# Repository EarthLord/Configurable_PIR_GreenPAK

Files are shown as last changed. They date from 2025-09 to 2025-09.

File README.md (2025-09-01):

# Project _PIR<sup>PAK</sup>_

### Objective

Create a PIR (Passive InfraRed) sensor system to detect movement using low cost AnalogPAK IC from Renesas (SLG47001). PIR sensors detect motion of heat, thus are used in security systems, building automation and wildlife conservation industries extensively. The sensitivity of sensing of movement is configurable by users using an `UP` and `DOWN` button.

### SLG47001 design 
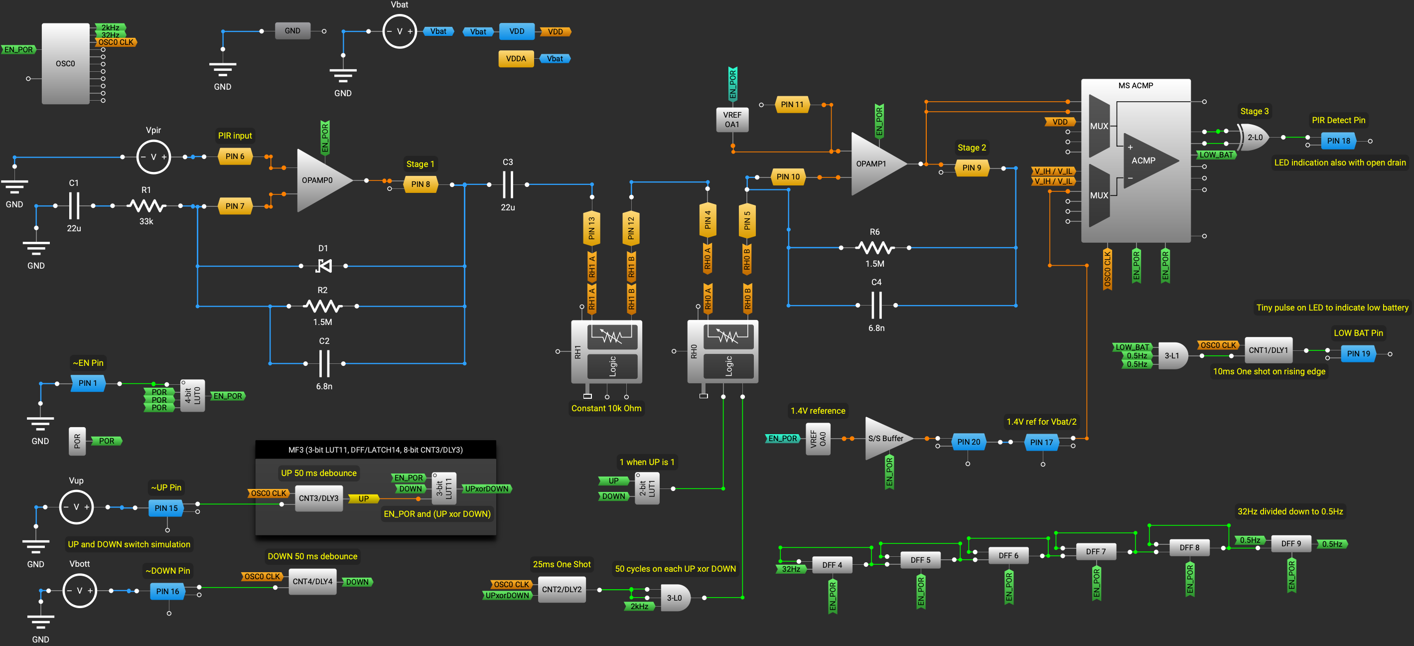
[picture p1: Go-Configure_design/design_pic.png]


### Schematic
schematic.pdf

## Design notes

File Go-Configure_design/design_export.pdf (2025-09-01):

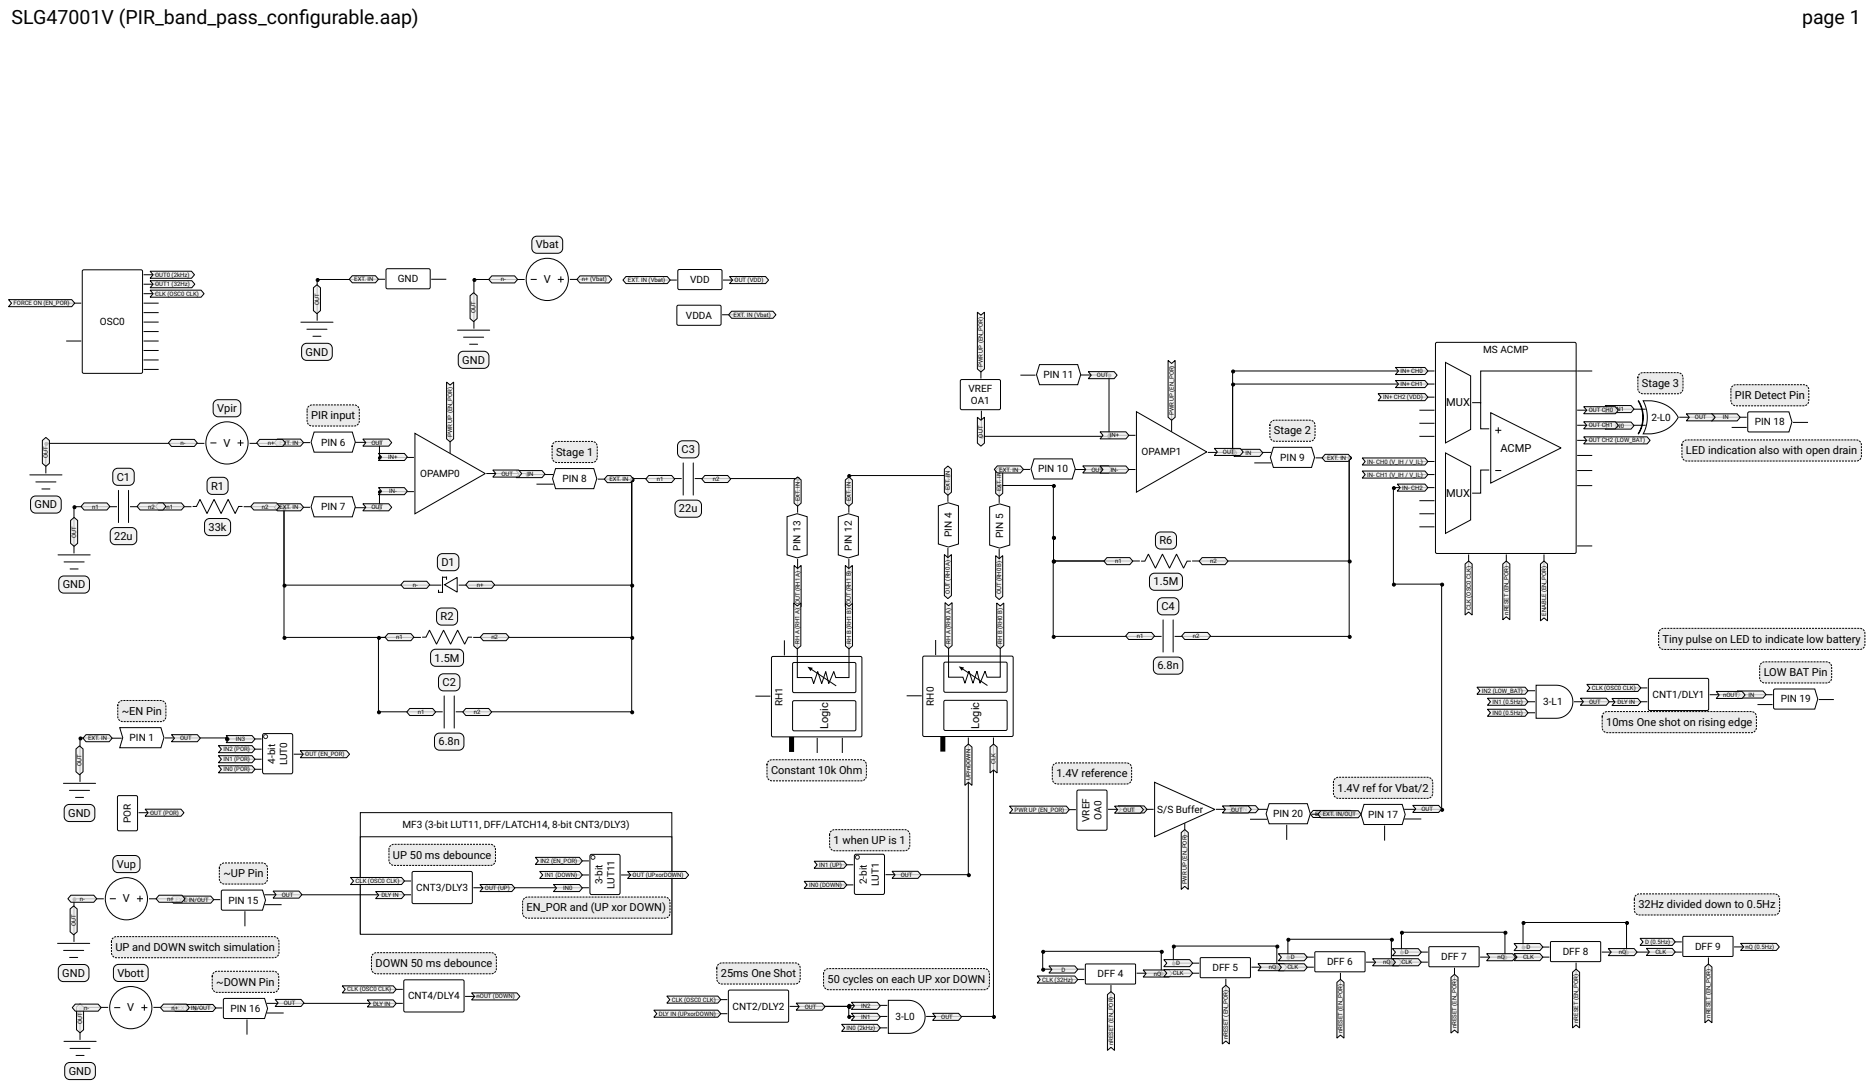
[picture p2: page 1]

LED indication also with open drain

OUT (RH0 A) EXT. IN PIN 4

OUT (RH0 B) EXT. IN PIN 5

OUT (RH1 A) EXT. IN PIN 13

OUT (RH1 B) EXT. IN PIN 12

Tiny pulse on LED to indicate low battery

DLY IN
10ms One shot on rising edge

EN_POR and (UP xor DOWN)

UP and DOWN switch simulation

50 cycles on each UP xor DOWN

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
e I/O selection | Digital input In mode | Digital in with Schmitt trig
| g e r
O u t m o d e | N o n e
R e sis t o r | P ull U p
R e sis t o r v alu e | 1 M

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
P r o p e r ty | Va l u e
Min. v alu e ( V ) | 2.4 0
Ty p. v alu e ( V ) | 3.0 0
M a x. v alu e ( V ) | 3.4 0

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
P r o p e r ty | Va l u
e I/O selection | Analog input/output In mode | Analog input/output Out mode | Analog input/output Resistor | Floating PIN 5 (RH0_B/GPI2) Property | Value I/O selection | Analog input/output In mode | Analog input/output Out mode | Analog input/output Resistor | Floating PIN 6 (OA0+) Label: "PIR input" Property | Value I/O selection | Analog input/output In mode | Analog input/output Out mode | Analog input/output

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
e I/O selection | Analog input/output In mode | Analog input/output Out mode | Analog input/output PIN 8 (OA0_OUT) Label: "Stage 1" Property | Value I/O selection | Analog input/output In mode | Analog input/output Out mode | Analog input/output PIN 9 (OA1_OUT) Label: "Stage 2" Property | Value I/O selection | Analog input/output In mode | Analog input/output Out mode | Analog input/output PIN 10 (OA1-) Property | Value I/O selection | Analog input/output In mode | Analog input/output Out mode | Analog input/output PIN 11 (OA1+) Property | Value I/O selection | Analog input/output In mode | Analog input/output Out mode | Analog input/output PIN 12 (RH1_B/GPI3) Property | Value I/O selection | Analog input/output In mode | Analog input/output Out mode | Analog input/output Resistor | Pull Down Resistor value | 1M

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
e I/O selection | Analog input/output In mode | Analog input/output Out mode | Analog input/output Resistor | Floating VDDA (PIN 14) Property | Value Min. value (V) | N/D Typ. value (V) | N/D Max. value (V) | N/D PIN 15 (GPIO0) Label: "~UP Pin" Property | Value I/O selection | Digital input In mode | Digital in with Schmitt trig
| g e r
O u t m o d e | N o n e
R e sis t o r | P ull U p
R e sis t o r v alu e | 1 M

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
P r o p e r ty | Va l u
| Digital input In mode Digital in with Schmitt trig e I/O selection
| g e r
O u t m o d e | N o n e
R e sis t o r | P ull U p
R e sis t o r v alu e | 1 M

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
P r o p e r ty | Va l u
| Analog input/output In mode Analog input/output Out mode Analog input/output Resistor Floating e I/O selection

S

L

G

V

(

### PIR

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
### ble.a

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
e I/O selection | Digital output In mode | None Out mode | 3.2x open drain NMOS Resistor | Pull Up Resistor value | 100K PIN 19 (SDA/GPIO5) Label: "LOW BAT Pin" Property | Value I/O selection | Digital output In mode | None Out mode | 3.2x open drain NMOS Resistor | Pull Up Resistor value | 100K PIN 20 (GPIO3) Property | Value I/O selection | Analog input/output In mode | Analog input/output Out mode | Analog input/output Resistor | Floating Digital Rheostat0 Property | Value Enable status | Enable EPG data to Rheostat | Disable Data mapping selection | MSB Active level for UP/DOWN | Up when HIGH Resistance (initial data) | 500 Calculated resistance | ~49.618 kOhm

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
e le

v

el f

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
(initial d

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

O

PA

M

P

1

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
P r o p e r ty | Va l u e
E n a ble s ele c tio n | F r o m r e gis t e r
R e gis t e r e n a ble | V r e f e n a
ble Input voltage selection | 2.016 V Output selection | 1408 mV High side VREF selection | Disable VREF LPF | Disable VREF OPAMP1 Property
| Va l u e
E n a ble s ele c tio n | F r o m m a t rix
R e gis t e r e n a ble | V r e f e n a
| VDD Output selection VDD * (32 / ble Input voltage selection
| 6 3 )
V R E F L P F | E n a ble

M

S

A

C

M

P

P r o p e r ty | Va l u e
M o d e s ele c tio n | S a m plin g
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
el A

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
plin

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
X in

p

u

t

S

a

m

plin

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

VDD Channel 0 IN+ gain Disable IN+ source OA1 IN- Low to High source VDD * (4 ble Input voltage selection

8

/

6

3

VDD * (48 / 63) Hysteresis - Output polarity Q Channel 1 IN+ gain Disable IN+ source OA1 IN- Low to High source VDD * (16 / 63) IN- High to Low source VDD * (16 / 63) Hysteresis - Output polarity Q Channel 2 IN+ gain x0.5 IN+ source VDD IN- Low to High source Ext. Vref (PIN 1 ) IN- High to Low source

7 ( G PIO 2 )

Ext. Vref (PIN 17 (GPIO2)) Hysteresis - Output polarity nQ ) IN- High to Low source

## 2-bit LUT0/DFF/LATCH0 Label: "Stage 3"

IN1 | IN0 | OUT
0 | 0 | 0
0 | 1 | 1
1 | 0 | 1
1 | 1 | 0
Property | Value
Type | LUT
Standard gates | XOR

## 2-bit LUT1/DFF/LATCH1 Label: "1 when UP is 1"

IN1 | IN0 | OUT
0 | 0 | 0
0 | 1 | 0
1 | 0 | 1
1 | 1 | 1
Property | Value
Type | LUT
Standard gates | | Defined by user

## 3-bit LUT0/DFF/LATCH2 Label: "50 cycles on each UP xor DOWN"

IN2 | IN1 | IN0 | OUT
0 | 0 | 0 | 0
0 | 0 | 1 | 0
0 | 1 | 0 | 0
0 | 1 | 1 | 0
1 | 0 | 0 | 0
1 | 0 | 1 | 0
1 | 1 | 0 | 0
1 | 1 | 1 | 1
Property | Value
Type | LUT
Standard gates | AND

## 3-bit LUT1/DFF/LATCH3

IN2 | IN1 | IN0 | OUT
0 | 0 | 0 | 0
0 | 0 | 1 | 0
0 | 1 | 0 | 0
0 | 1 | 1 | 0
1 | 0 | 0 | 0
1 | 0 | 1 | 0
1 | 1 | 0 | 0
1 | 1 | 1 | 1
Property | Value
Type | LUT
Standard gates | AND

## 3-bit LUT2/DFF/LATCH4

Property | Value
Type | DFF / LATCH
Mode | DFF
nSET/nRESET option | nRESET
Initial polarity | Low
Q output polarity | Inverted (nQ)
Active level for RST/SET | Low level

## 3-bit LUT3/DFF/LATCH5

Property | Value
Type | DFF / LATCH
Mode | DFF
nSET/nRESET option | nRESET
Initial polarity | Low
Q output polarity | Inverted (nQ)
Active level for RST/SET | Low level

## 3-bit LUT4/DFF/LATCH6/Shift Register 0

Property | Value
Type | DFF / LATCH
Mode | DFF
nSET/nRESET option | nRESET
Initial polarity | Low
Q output polarity | Inverted (nQ)
Active level for RST/SET | Low level

## 3-bit LUT5/DFF/LATCH7/Shift Register 1

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

## 3-bit LUT6/DFF/LATCH8/Shift Register 2

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

## 3-bit LUT7/DFF/LATCH9/Shift Register 3 Label: "32Hz divided down to 0.5Hz"

Property | Value
Type | DFF / LATCH
Mode | DFF
nSET/nRESET option | nRESET
Initial polarity | Low
Q output polarity | Inverted (nQ)
Active level for RST/SET | Low level
SLG47001V (PIR_band_pass_configurable.aap) | page 4

## 4-bit LUT0/DFF/LATCH10

IN3 | IN2 | IN1 | IN0 | OUT
0 | 0 | 0 | 0 | 0
0 | 0 | 0 | 1 | 0
0 | 0 | 1 | 0 | 0
0 | 0 | 1 | 1 | 0
0 | 1 | 0 | 0 | 0
0 | 1 | 0 | 1 | 0
0 | 1 | 1 | 0 | 0
0 | 1 | 1 | 1 | 1
1 | 0 | 0 | 0 | 0
1 | 0 | 0 | 1 | 0
1 | 0 | 1 | 0 | 0
1 | 0 | 1 | 1 | 0
1 | 1 | 0 | 0 | 0
1 | 1 | 0 | 1 | 0
1 | 1 | 1 | 0 | 0
1 | 1 | 1 | 1 | 0
Property | Value
Type | LUT
Standard gates | Defined by user

## MF1 (3-bit LUT9, DFF/LATCH12, 8-bit CNT1/DLY1)

## 8-bit CNT1/DLY1 (MF1) Label: "10ms One shot on rising edge"

Property | Value
Mode | One shot
Counter data | 20
Pulse width (typical) | 10.2539 ms
Edge mode select | Rising
DLY IN init. value | Initial 0
Output polarity | Inverted (nOUT)
Mode signal SYNC | Bypass
Clock source | OSC0
Clock frequency | 2.048 kHz

## MF2 (3-bit LUT10, DFF/LATCH13, 8-bit CNT2/DLY2)

## 8-bit CNT2/DLY2 (MF2) Label: "25ms One Shot"

Property | Value
Mode | One shot
Counter data | 50
Pulse width (typical) | 24.9023 ms
Edge mode select | Rising
DLY IN init. value | Initial 0
Output polarity | Non-inverted (OUT)
Mode signal SYNC | Bypass
Clock source | OSC0
Clock frequency | 2.048 kHz

## MF3 (3-bit LUT11, DFF/LATCH14, 8-bit CNT3/DLY3)

## 3-bit LUT11 (MF3) Label: "EN_POR and (UP xor DOWN)"

IN2 | IN1 | IN0 | OUT
0 | 0 | 0 | 0
0 | 0 | 1 | 0
0 | 1 | 0 | 0
0 | 1 | 1 | 0
1 | 0 | 0 | 0
1 | 0 | 1 | 1
1 | 1 | 0 | 1
1 | 1 | 1 | 0
Property | Value
Standard gates | Defined by user

## 8-bit CNT3/DLY3 (MF3) Label: "UP 50 ms debounce"

Property | Value
Mode | Delay
Counter data | 101
Delay time (typical) | 49.8047 ms
Edge mode select | Both
DLY IN init. value | Bypass the initial
Output polarity | Non-inverted (OUT)
Mode signal SYNC | Bypass
Clock source | OSC0
Clock frequency | 2.048 kHz

## MF4 (3-bit LUT12, DFF/LATCH15, 8-bit CNT4/DLY4)

## 8-bit CNT4/DLY4 (MF4) Label: "DOWN 50 ms debounce"

Property | Value
Mode | Delay
Counter data | 101
Delay time (typical) | 49.8047 ms
Edge mode select | Both
DLY IN init. value | Bypass the initial
Output polarity | Inverted (nOUT)
Mode signal SYNC | Bypass
Clock source | OSC0
Clock frequency | 2.048 kHz

## OSC0

Property | Value
Control pin mode | Force on
OSC power mode | Force Power On
Clock selector | OSC
'OSC0' frequency | 2.048 kHz
'CLK' predivider by | 1
'OUT0' second divider by | 1
'OUT1' second divider by | 64

## Sink/Source Buffer

Property | Value
Power up source | From register
Power up register | Enable
Input selection | OA0 VREF
Input selection from VREF | 1408 mV
SLG47001V (PIR_band_pass_configurable.aap) | page 5

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
Ele m e n t | C a p a cit o r
C a p a cit a n c e | 6.8 n F
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
allel R

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
allel R

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
allel R

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

V

b

a

t

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

m

a

x

3.3

V
T lo w | 1.7 s
T

risin

g

5

m

s
T hig h | 5 s
T f allin g | 5 m s

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

d
Ris e tim e | 1 μ s
F all tim e | 1 μ s

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
1 0 0 m s | 3 V
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
1 0 0 m s | 3 V
1 0 0 m s | 0 V
5 0 0 μ s | 3 V

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
D u ra t i o n | Vo l t a g e
1 0 0 0 m s | 3.3 V
5 m s | 0 V
5 m s | 3.3 V
5 m s | 0 V
5 m s | 3.3 V
1 0 0 m s | 0 V
1 0 0 m s | 3.3 V
1 0 0 m s | 0 V
1 0 0 m s | 3.3 V
1 0 0 m s | 0 V
1 0 0 m s | 3.3 V

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
n. | Typ. | M a
x. VDD | 2.40 | 3.00 | 3.40 Temperature (°C): | -20.00 | 25.00 | 50.00 General Settings Force bandgap on | Enable GPIO quick charge | Disable Lock status | Unlocked Pattern ID | 1

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
X: 0

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
C: 6

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
X: 0

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
C: 6

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
X: 0

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
C: 6

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
X: 0

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
C: 6

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
X: 0

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
C: 6

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
X: 0

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
C: 6

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
X: 0

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
C: 6

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
X: 0

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
C: 6

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
X: 0

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
C: 6

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
X: 0

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
C: 6

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
X: 0

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
C: 6

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
X: 0

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
C: 6

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
X: 0

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
C: 6

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
X: 0

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
C: 6

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
X: 0

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
C: 6

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
X: 0

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
C: 6

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
X: 0

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
C: 6

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
X: 0

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
C: 6

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
X: 0

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
C: 6

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
X: 0

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
C: 6

2

`

b

3

+

8 -bit C N T 4 / D LY 4 ( M F 4 ) -> n O U T | D O W N | H E X: 0 x 3 E ` b 4 D E C: 6 2 ` b 4 | +
3 -bit L U T 1 2 ( M F 4 ) -> O U T | | H E X: 0 x 3 E ` b 5 D E C: 6 2 ` b 5 | -
PIN 1 8 ( S C L / G PIO 4 ) -> O U T /I2 C -> O U T 8 | | H E X: 0 x 3 E ` b 6 D E C: 6 2 ` b 6 | -
PIN 1 9 ( S D A / G PIO 5 ) -> O U T /I2 C -> O U T 9 | | H E X: 0 x 3 E ` b 7 D E C: 6 2 ` b 7
- I2C -> OUT0 | HEX: 0x3F`b0 DEC: 63`b0 | - I2C -> OUT1 | HEX: 0x3F`b1 DEC: 63`b1 | - I2C -> OUT2/EPG -> OUT2 | HEX: 0x3F`b2 DEC: 63`b2 | - I2C -> OUT3/EPG -> OUT3 | HEX: 0x3F`b3 DEC: 63`b3 | - I2C -> OUT4/EPG -> OUT4 | HEX: 0x3F`b4 DEC: 63`b4 | - I2C -> OUT5/EPG -> OUT5 | HEX: 0x3F`b5 DEC: 63`b5 | - I2C -> OUT6/EPG -> OUT6 | HEX: 0x3F`b6 DEC: 63`b6 | - I2C -> OUT7/EPG -> OUT7 | HEX: 0x3F`b7 DEC: 63`b7 | - PIN 4 (RH0_A/GPI1) -> OUT | RH0 A | HEX: 0x40`b0 DEC: 64`b0 | - PIN 5 (RH0_B/GPI2) -> OUT | RH0 B | HEX: 0x40`b1 DEC: 64`b1 | - PIN 12 (RH1_B/GPI3) -> OUT | RH1 B | HEX: 0x40`b2 DEC: 64`b2 | - PIN 13 (RH1_A/GPI4) -> OUT | RH1 A | HEX: 0x40`b3 DEC: 64`b3 | - PIN 1 (GPI0) -> OUT | NET1 | HEX: 0x40`b4 DEC: 64`b4 | + PIN 15 (GPIO0) -> OUT | NET49 | HEX: 0x40`b5 DEC: 64`b5 | + PIN 16 (GPIO1) -> OUT | NET28 | HEX: 0x40`b6 | +

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
C: 6

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
X: 0

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
C: 6

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
X: 0

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
C: 6

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
X: 0

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
C: 6

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
X: 0

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
C: 6

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
X: 0

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
C: 6

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
X: 0

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
C: 6

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
X: 0

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
C: 6

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
X: 0

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
C: 6

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
X: 0

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
C: 6

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
X: 0

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
C: 6

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
X: 0

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
C: 6

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
X: 0

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
C: 6

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
X: 0

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
C: 6

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
X: 0

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
C: 6

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
X: 0

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
C: 6

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
X: 0

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
C: 6

7

`

b

2

+

Digit

al R

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
X: 0

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
C: 6

7

`

b

3

Digit

al R

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
X: 0

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
C: 6

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
X: 0

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
C: 6

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
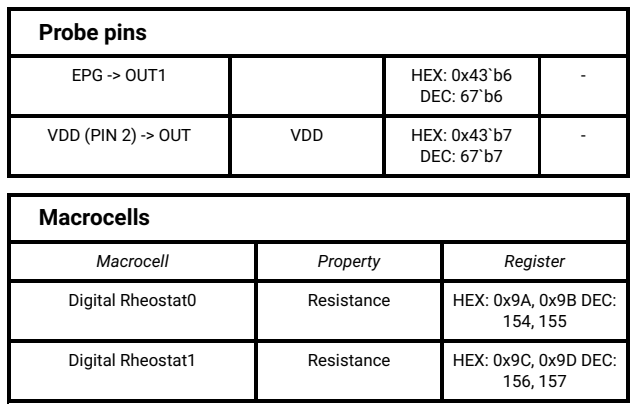
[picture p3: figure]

E P G -> O U T 1 | | H E X: 0 x 4 3 ` b 6 D E C: 6 7 ` b 6 | -
V D D ( PIN 2 ) -> O U T | V D D | H E X: 0 x 4 3 ` b 7 D E C: 6 7 ` b 7 | -
M a c r o c e l l | P r o p e r ty | R e g i s t e r
Digit al R h e o s t a t 0 | R e sis t a n c e | H E X: 0 x 9 A , 0 x 9 B D E C: 154, 155
Digit al R h e o s t a t 1 | R e sis t a n c e | H E X: 0 x 9 C , 0 x 9 D D E C: 156, 157

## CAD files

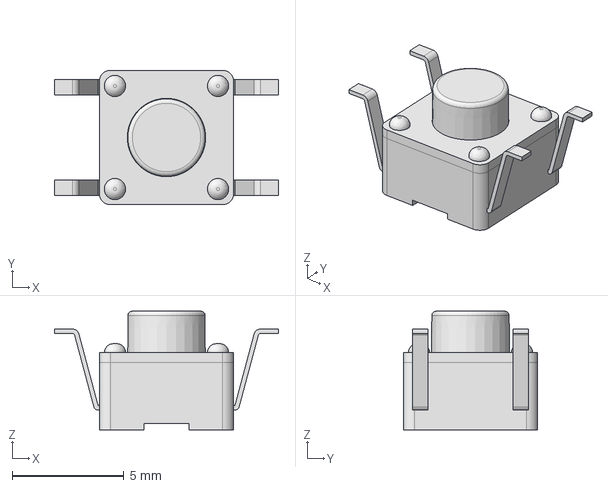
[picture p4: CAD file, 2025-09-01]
3D_models/RT3301AF100Q.stp
10.0 x 6.00 x 5.30 mm

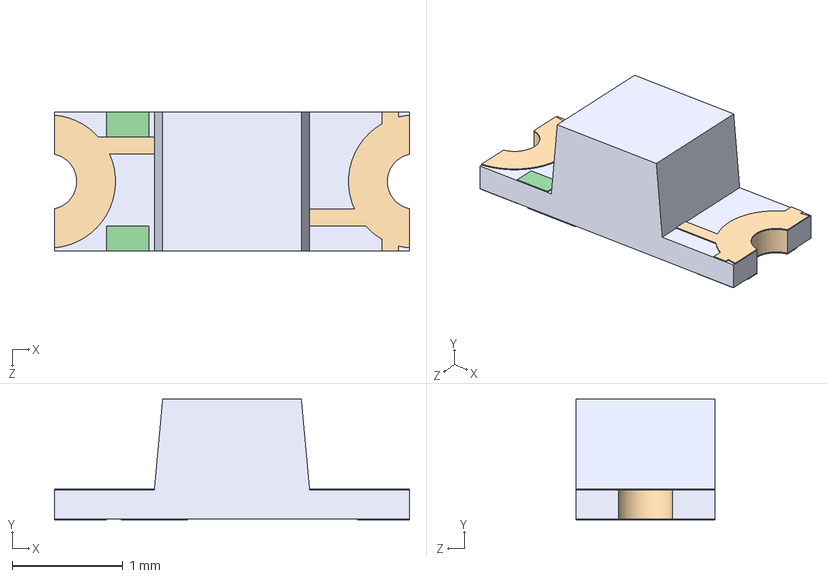
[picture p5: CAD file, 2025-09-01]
3D_models/5990Kxx_reverse_LED.stp
3.20 x 1.09 x 1.25 mm
599-0K10-107F_2
599-0K10-107F_7
599-0K10-107F_4
599-0K10-107F_6
599-0K10-107F
599-0K10-107F_1
599-0K10-107F_3
599-0K10-107F_5

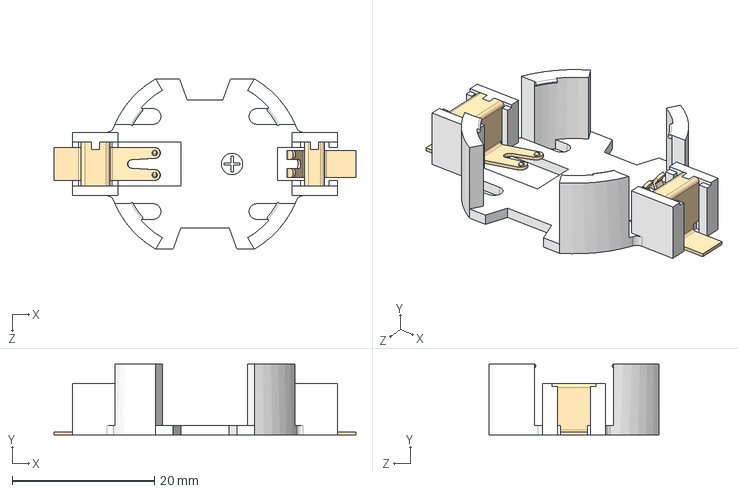
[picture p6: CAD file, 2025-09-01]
3D_models/BU2477SM-JJ-GTR.STEP
42.5 x 9.92 x 24.0 mm

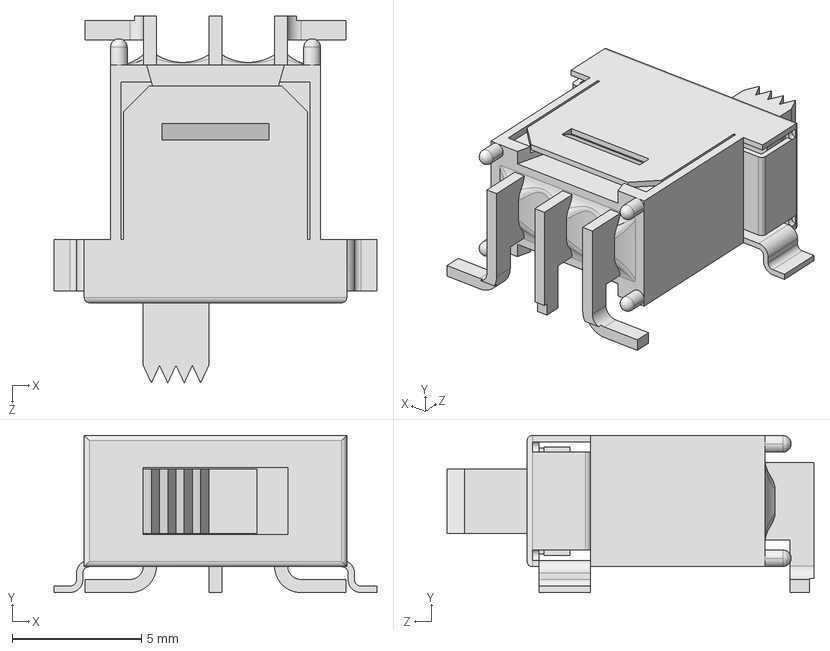
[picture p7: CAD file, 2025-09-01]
3D_models/500ASSP1SM6QE.step
12.5 x 6.08 x 14.2 mm

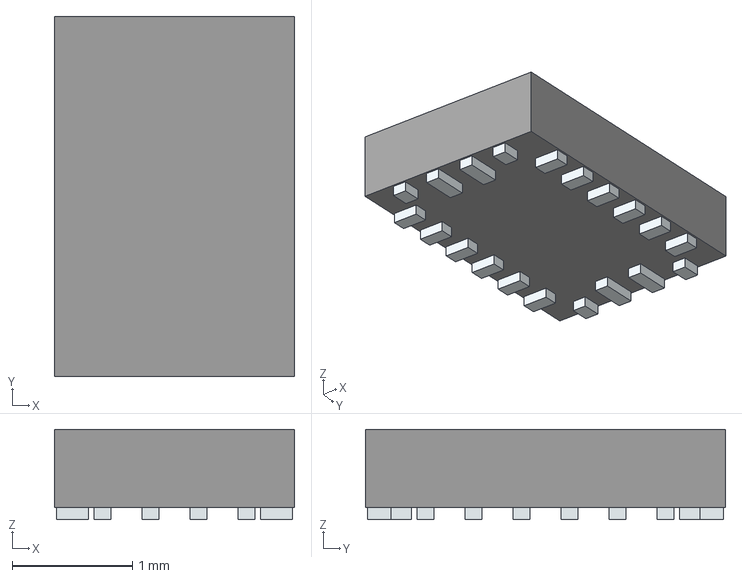
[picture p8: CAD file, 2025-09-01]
3D_models/SLG47001V.stp
2.00 x 3.00 x 0.75 mm
Pins

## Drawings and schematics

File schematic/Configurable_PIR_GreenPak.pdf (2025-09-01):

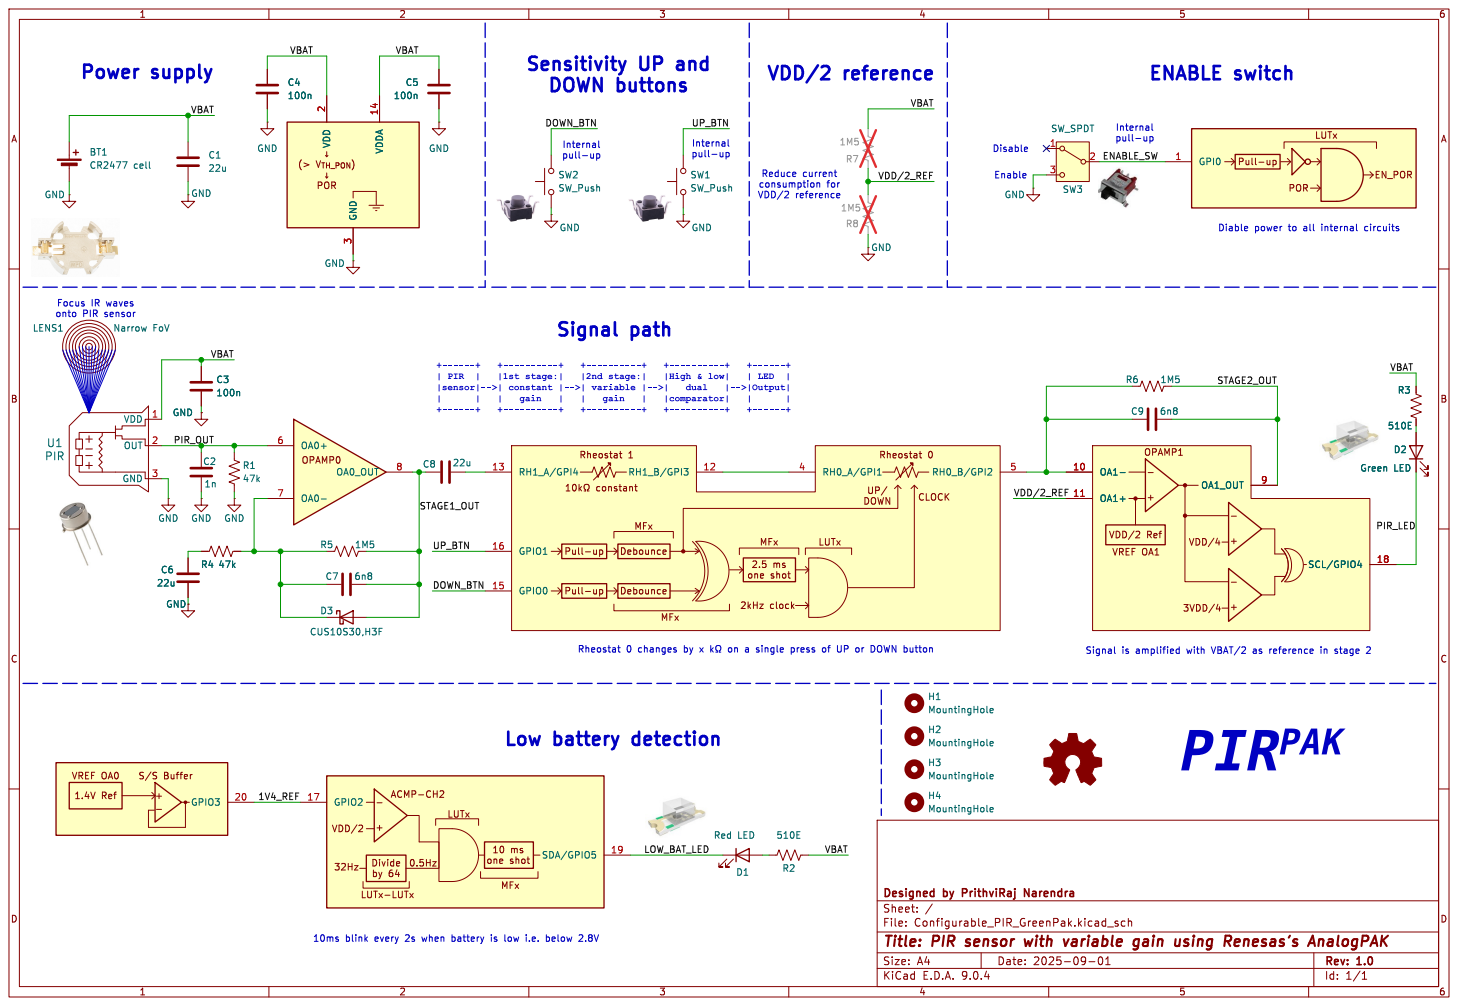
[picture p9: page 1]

Rheostat 0 changes by x þÿk©on a single press of UP or DOWN button Signal path

H4 MountingHole H3 MountingHole H2 MountingHole VREF OA0

Id: 1/1 Title: PIR sensor with variable gain using Renesas's AnalogPAK

10ms blink every 2s when battery is low i.e. below 2.8V

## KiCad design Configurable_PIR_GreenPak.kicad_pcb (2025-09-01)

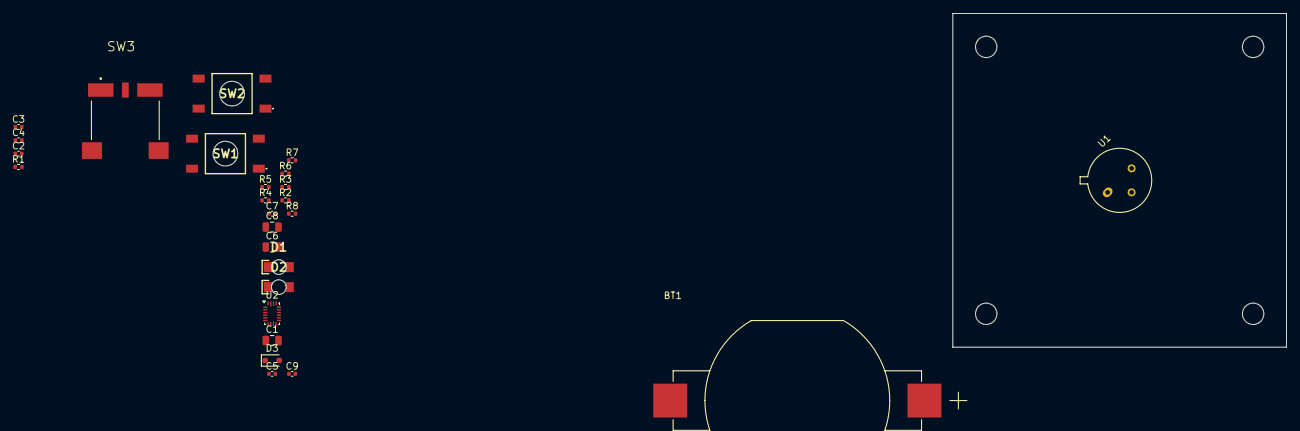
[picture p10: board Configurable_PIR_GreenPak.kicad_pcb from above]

Board: 4 copper layers, 50.0 x 50.0 mm, 30 parts (0 on the bottom side), 18 nets, no tracks yet.

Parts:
BT1: Battery_Cell; MPD_BU2477SM-JJ-GTR
C1, C6, C8: 22u; C_0805_2012Metric
C2: 1n; C_0402_1005Metric
C3, C4, C5: 100n; C_0402_1005Metric
C7, C9: 6n8; C_0402_1005Metric
D1: Red LED; 5990Kxx_reverse_LED
D2: Green LED; 5990Kxx_reverse_LED
D3: CUS10S30,H3F; D_SOD-323
H1, H2, H3, H4: MountingHole; MountingHole_3.2mm_M3
R1, R4: 47k; R_0402_1005Metric
R2, R3: 510E; R_0402_1005Metric
R5, R6, R7, R8: 1M5; R_0402_1005Metric
SW1, SW2: SW_Push; RT3301AF100Q
SW3: SW_SPDT; SW_500ASSP1SM6QE
U1: PIR; TO-5-3
U2: SLG47001V; Renesas_UQFN-20_2x3mm_P0.4mm_LayoutBorder4x6y

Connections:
/DOWN_BTN: SW2.2, U2.15 (GPIO0)
/ENABLE_SW: SW3.2 (B), U2.1 (GPI0)
/LOW_BAT_LED: D1.1 (K), U2.19 (SDA/GPIO5)
/PIR_LED: D2.1 (K), U2.18 (SCL/GPIO4)
/PIR_OUT: C2.1, R1.1, U1.2 (OUT), U2.6 (OA0+)
/STAGE1_OUT: C7.2, C8.1, D3.2 (A), R5.2, U2.8 (OA0_OUT)
/STAGE2_OUT: C9.2, R6.2, U2.9 (OA1_OUT)
/UP_BTN: SW1.2, U2.16 (GPIO1)
/VBAT: BT1.P (+), C1.1, C3.1, C4.1, C5.1, R2.2, R3.2, R7.2, U1.1 (VDD), U2.2 (VDD), U2.14 (VDDA)
/VDD/2_REF: R7.1, R8.2, U2.11 (OA1+)
GND: BT1.N, C1.2, C2.2, C3.2, C4.2, C5.2, C6.2, R1.2, R8.1, SW1.1, SW2.1, SW3.3 (C), U1.3 (GND), U2.3 (GND)
unnamed: C6.1, R4.1
unnamed: D1.2 (A), R2.1
unnamed: D2.2 (A), R3.1
unnamed: C7.1, D3.1 (K), R4.2, R5.1, U2.7 (OA0-)
unnamed: U2.4 (RH0_A/GPI1), U2.12 (RH1_B/GPI3)
unnamed: C9.1, R6.1, U2.5 (RH0_B/GPI2), U2.10 (OA1-)
unnamed: C8.2, U2.13 (RH1_A/GPI4)

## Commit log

2025-09-01 Create initial commit of PIRPAK project
    Schematic finished with part numbers assigned to all parts except passives
    Basic readme created
    [Configurable_PIR_GreenPak.kicad_pcb, Configurable_PIR_GreenPak.kicad_sch]
2025-09-01 Add schematic pdf in schematic folder and show it in README
2025-09-01 Add 3D models of button, switch, LED, SLG47001V and cell holder
    [500ASSP1SM6QE.step, 5990Kxx_reverse_LED.stp, BU2477SM-JJ-GTR.STEP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]
2025-09-01 Add footprints of all parts
2025-09-01 Create basic PCB layout after assigning footprints to all schematic symbols
    [Configurable_PIR_GreenPak.kicad_pcb, Configurable_PIR_GreenPak.kicad_sch]
